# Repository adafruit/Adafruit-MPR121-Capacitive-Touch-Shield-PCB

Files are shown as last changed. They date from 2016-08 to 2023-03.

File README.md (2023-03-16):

## Adafruit MPR121 Capacitive Touch Shield PCB
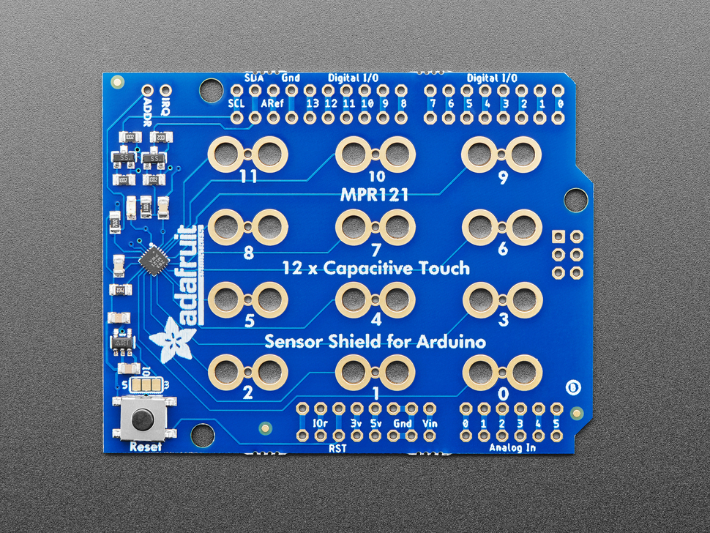
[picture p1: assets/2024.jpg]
<a href="http://www.adafruit.com/products/2024"><br/>
Click here to purchase one from the Adafruit shop</a>

This touch-able add on shield for Arduinos will inspire your next interactive project with 12 capacitive touch sensors. Capacitive touch sensing works by detecting when a person (or animal) has touched one of the sensor electrodes. Capacitive touch sensing used for stuff like touch-reactive tablets and phones, as well as control panels for appliances, which is where you may have used it before. This shield allows you to create electronics that can react to human touch, with up to 12 individual sensors.

The shield has 12 'figure 8' holes in it that can be gripped onto with alligator clip cables. Attach one side of the clip to the shield and the other side to something electrically conductive (like metal) or full of water (like vegetables or fruit!) Then start up our handy Arduino library to detect when the object is touched. That's pretty much it, very easy! For advanced users, you can also solder to a pad to make a slimmer & more permanent connection. Works great with any Arduino as it only uses the I2C pins (SCL & SDA).

It uses the same chip as our MPR121 12-Key Capacitive Touch Sensor Breakout so you can duplicate the library and code! We have examples for reading touches. Using an Arduino Leonardo and a little bit of creativity you can use it to turn touches into keyboard KeyUp/KeyDown presses (so you can make a veggie-keyboard) or pair it with our Music Maker shield to create an audio player that will play a sound per sensor (fruit drums!)

PCB files for the Adafruit MPR121 Capacitive Touch Shield. The format is EagleCAD schematic and board layout
- https://www.adafruit.com/product/2024

### License

Adafruit invests time and resources providing this open source design, please support Adafruit and open-source hardware by purchasing products from [Adafruit](https://www.adafruit.com)!

All text above must be included in any redistribution

Designed by Limor Fried/Ladyada for Adafruit Industries.
Creative Commons Attribution/Share-Alike, all text above must be included in any redistribution.
See license.txt for additional information.

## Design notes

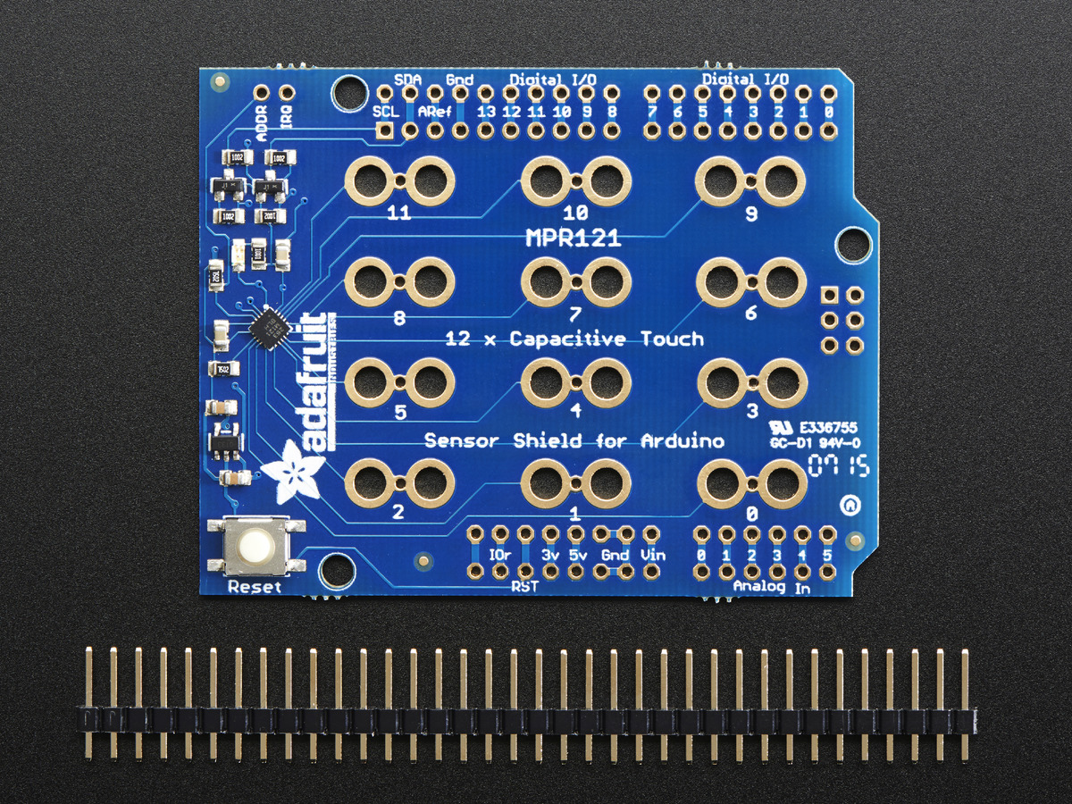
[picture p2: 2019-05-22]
assets/image.jpg

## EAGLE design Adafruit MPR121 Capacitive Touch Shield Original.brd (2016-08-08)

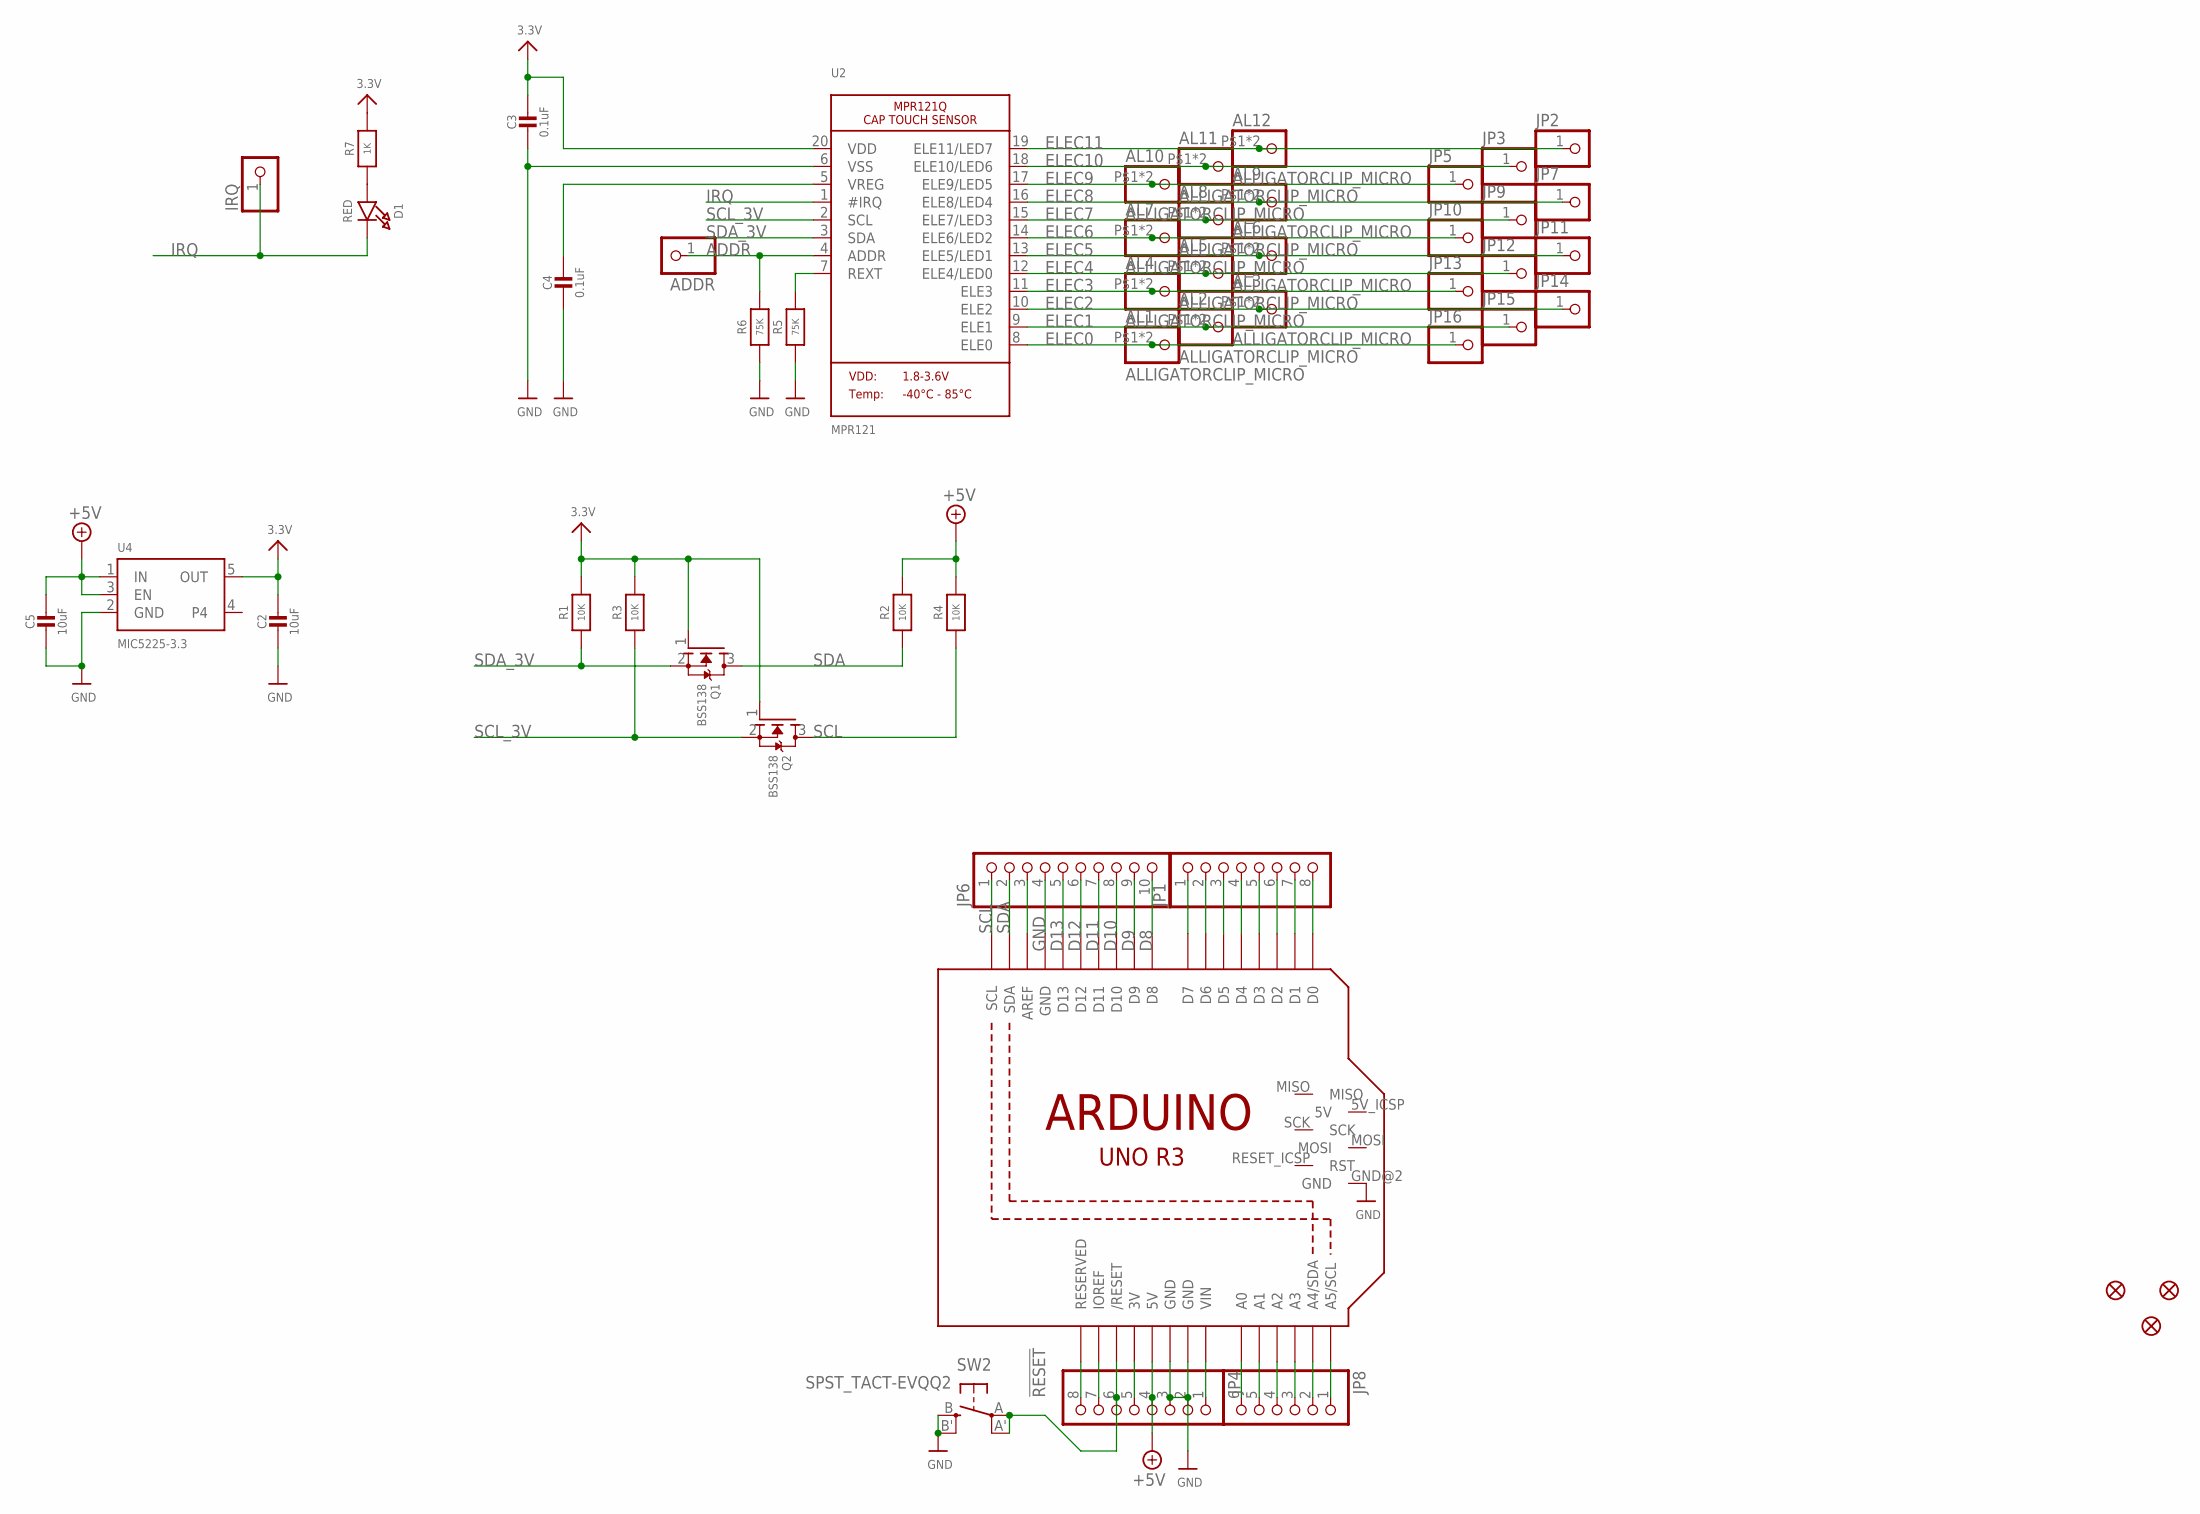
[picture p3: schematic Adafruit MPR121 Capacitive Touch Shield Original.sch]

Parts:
ADDR: HEADER-1X1ROUND; 1X01_ROUND
AL1, AL2, AL3, AL4, AL5, AL6, AL7, AL8, AL9, AL10, AL11, AL12: ALLIGATORCLIP_MICRO; ALLIGATORCLIP
C2, C5: 10uF; 0805-NO
C3, C4: 0.1uF; 0805-NO
D1: RED; CHIPLED_0805_NOOUTLINE
FID1, FID2, FID3: FIDUCIAL""; FIDUCIAL_1MM
IRQ: HEADER-1X1ROUND; 1X01_ROUND
JP1, JP4: PINHD-1X8CLEANBIG; 1X08-CLEANBIG
JP2, JP3, JP5, JP7, JP9, JP10, JP11, JP12, JP13, JP14, JP15, JP16: HEADER-1X1ROUND; 1X01_ROUND
JP6: HEADER-1X1070MIL; 1X10_ROUND70
JP8: PINHD-1X6CB; 1X06-CLEANBIG
Q1, Q2: BSS138; SOT23-WIDE
R1, R2, R3, R4: 10K; 0805-NO
R5, R6: 75K; 0805-NO
R7: 1K; 0805-NO
SW2: SPST_TACT-EVQQ2; EVQ-Q2
U2: MPR121; QFN20_3MM_NOTHERMAL
U4: MIC5225-3.3; SOT23-5
U$41: ARDUINO_R3_ICSP; ARDUINOR3_ICSP

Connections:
3.3V: C2.1, C3.1, Q1.1 (G), Q2.1 (G), R1.2, R3.2, R7.2, U2.20 (VDD), U4.5 (OUT)
!RESET: JP4.6, SW2.A, SW2.A' (P1), U$41.RESET (/RESET)
+3V: JP4.5, U$41.3V
+5V: C5.1, JP4.4, R2.2, R4.2, U4.1 (IN), U4.3 (EN), U$41.5V
A0: JP8.6, U$41.A0
A1: JP8.5, U$41.A1
A2: JP8.4, U$41.A2
A3: JP8.3, U$41.A3
A4: JP8.2, U$41.A4 (A4/SDA)
A5: JP8.1, U$41.A5 (A5/SCL)
ADDR: ADDR.1, R6.2, U2.4 (ADDR)
AREF: JP6.3, U$41.AREF
D0: JP1.8, U$41.D0
D1: JP1.7, U$41.D1
D2: JP1.6, U$41.D2
D3: JP1.5, U$41.D3
D4: JP1.4, U$41.D4
D5: JP1.3, U$41.D5
D6: JP1.2, U$41.D6
D7: JP1.1, U$41.D7
D8: JP6.10, U$41.D8
D9: JP6.9, U$41.D9
D10: JP6.8, U$41.D10
D11: JP6.7, U$41.D11
D12: JP6.6, U$41.D12
D13: JP6.5, U$41.D13
ELEC0: AL1.P$1, AL1.P$2, JP16.1, U2.8 (ELE0)
ELEC1: AL2.P$1, AL2.P$2, JP15.1, U2.9 (ELE1)
ELEC2: AL3.P$1, AL3.P$2, JP14.1, U2.10 (ELE2)
ELEC3: AL4.P$1, AL4.P$2, JP13.1, U2.11 (ELE3)
ELEC4: AL5.P$1, AL5.P$2, JP12.1, U2.12 (ELE4/LED0)
ELEC5: AL6.P$1, AL6.P$2, JP11.1, U2.13 (ELE5/LED1)
ELEC6: AL7.P$1, AL7.P$2, JP10.1, U2.14 (ELE6/LED2)
ELEC7: AL8.P$1, AL8.P$2, JP9.1, U2.15 (ELE7/LED3)
ELEC8: AL9.P$1, AL9.P$2, JP7.1, U2.16 (ELE8/LED4)
ELEC9: AL10.P$1, AL10.P$2, JP5.1, U2.17 (ELE9/LED5)
ELEC10: AL11.P$1, AL11.P$2, JP3.1, U2.18 (ELE10/LED6)
ELEC11: AL12.P$1, AL12.P$2, JP2.1, U2.19 (ELE11/LED7)
GND: C2.2, C3.2, C4.2, C5.2, JP4.2, JP4.3, JP6.4, R5.1, R6.1, SW2.B (S), SW2.B' (S1), U2.6 (VSS), U4.2 (GND), U$41.GND, U$41.GND@1 (GND), U$41.GND@2 (GND), U$41.GND@3 (GND)
IORESET: JP4.7, U$41.IOREF
IRQ: D1.C, IRQ.1, U2.1 (#IRQ)
unnamed: C4.1, U2.5 (VREG)
unnamed: R5.2, U2.7 (REXT)
unnamed: D1.A, R7.1
NC: JP4.8, U$41.RESERVED
SCL: JP6.1, Q2.3 (D), R4.1, U$41.SCL
SCL_3V: Q2.2 (S), R3.1, U2.2 (SCL)
SDA: JP6.2, Q1.3 (D), R2.1, U$41.SDA
SDA_3V: Q1.2 (S), R1.1, U2.3 (SDA)
VIN: JP4.1, U$41.VIN

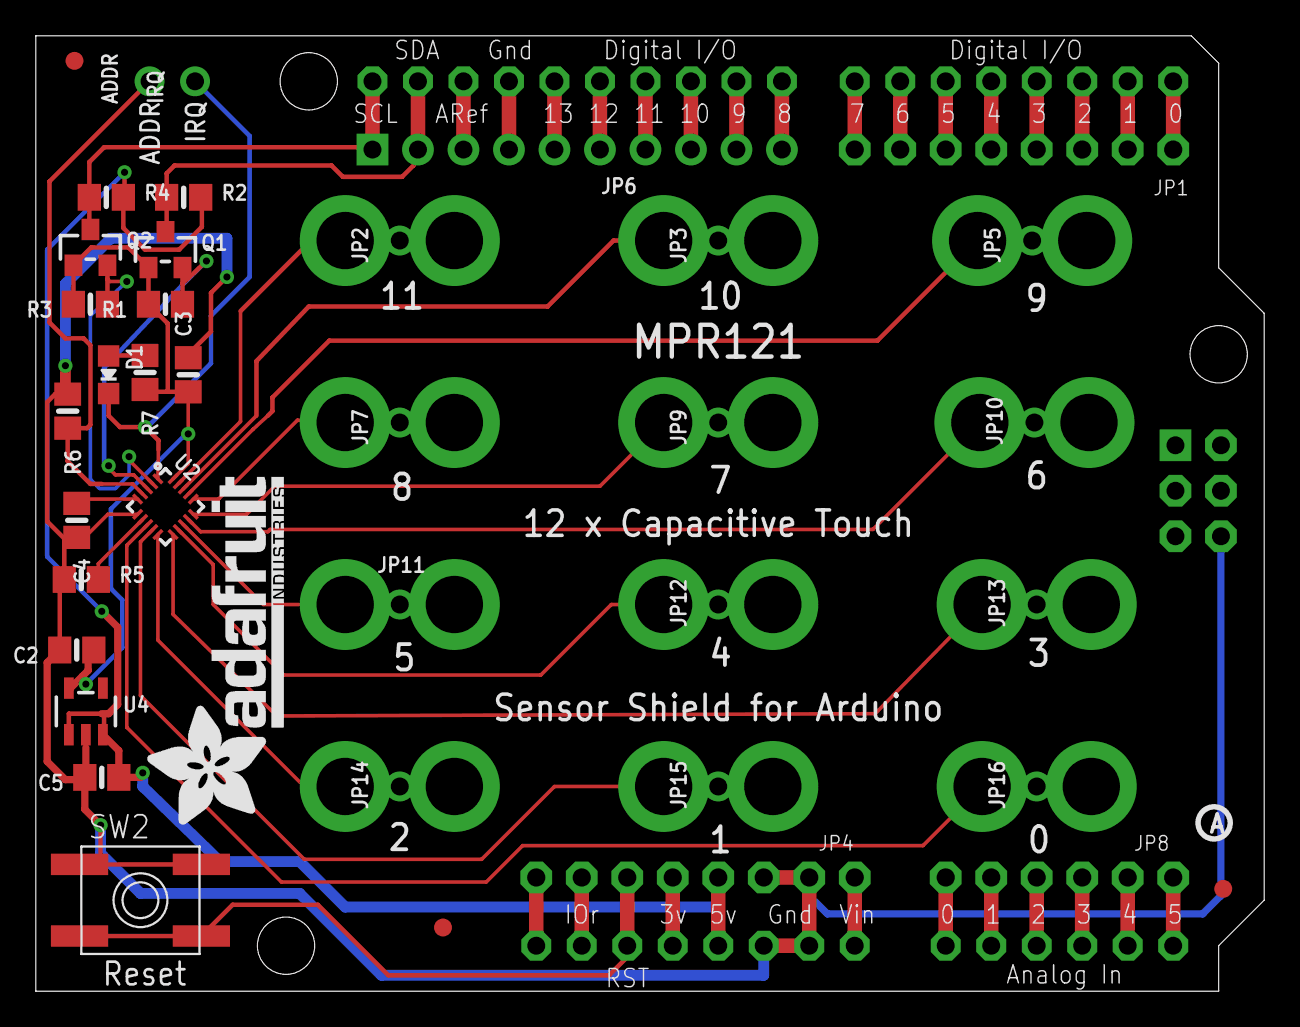
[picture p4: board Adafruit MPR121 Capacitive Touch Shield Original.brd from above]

Board: 2 copper layers, 68.6 x 53.3 mm, 53 parts (0 on the bottom side), 50 nets.

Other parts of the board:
U$8: PCBFEAT-REV-040
U$9: ADAFRUIT_TEXT_20MM
